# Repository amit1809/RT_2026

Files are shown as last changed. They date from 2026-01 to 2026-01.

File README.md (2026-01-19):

# RT-2025
CVHS Scioly Robot tour 2025

## Meeting recordings
https://drive.google.com/drive/folders/1aZCrpYOMPLyl0baIwFR1edMVWaG-CulE?usp=sharing

## Meeting notes
doces/RT-2025-meetings.pdf

## Example code
- stepper-without-lib
- stepper-with-lib
- buttons
- gyro (to be added)
- Robot (integrated with stepper lib, buttons)

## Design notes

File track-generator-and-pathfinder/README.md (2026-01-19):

# Track Generator

A Python tool for generating tracks and finding optimal paths.

- Track generation tool is from https://scioly.org/forums/viewforum.php?f=454
- Path finder tool is created deepseek v3 with vscode + cline

## Installation

1. Clone this repository:
   ```bash
   git clone https://github.com/frdeng/RT-2025.git
   cd RT-2025/track-generator
   ```

## Usage

The project contains two main scripts:

1. **pathfinder.py** - Contains pathfinding algorithms
2. **gen.py** - Contains track generation logic

Run the generator:
```bash
python gen.py
```

Run the pathfinder:
```bash
python pathfinder.py
```

## Contributing

Pull requests are welcome. For major changes, please open an issue first to discuss what you would like to change.

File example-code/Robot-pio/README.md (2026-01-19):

## Project Overview
### Key Components
- **src/main.cpp**: Main entry point for the robot, button and mode control
- **src/config.cpp**: Parameters and movement sequences
- **lib/Travel**: High-level movement sequencing and control
- **lib/Robot**: Motor control and movement execution
- **lib/IMU**: IMU integration and angle calculation
- **lib/Logger**: serial monitor logging and LCD screen display
- **lib/JY901**: IMU library

### Workflow
1. main.cpp loads parameters and sequences
1. Travel manages sequence execution
1. Robot controls stepper motors for movement, and IMU for angle feedback

## Setup

1. Install Visual Studio Code
https://visualstudio.microsoft.com/

1. Install PlatformIO IDE extension on VS Code
https://docs.platformio.org/en/latest/integration/ide/vscode.html#installation

1. Windows(not required for Mac)
Install ESP32 CP210x Driver: https://randomnerdtutorials.com/install-esp32-esp8266-usb-drivers-cp210x-windows/

## Operation Modes

1. **Test**
    - The robot will move with the test sequence defined in `src/config.cpp`

1. **Dry Run** (setDryRun(true))
    - Simulated movements
    - Timed turns

1. **Track Run**
    - The robot will move with the track sequence defined in `src/config.cpp`

## Quick Start

1. Copy configuration:
   ```bash
   cp src/config.cpp.example src/config.cpp
   ```

1. Adjust parameters in `src/config.cpp`
    - See Tuning Guide below

1. Modify `testSequence` or `runSequence` in `src/config.cpp` to define the sequence to run

1. Build and upload:
   - Click the upload button in the platformio IDE

5. Press the mode button on the robot to select the mode, place the robot on the track and press the start button to start the run

## Tuning Guide - `src/config.cpp`

1. **Basic Setup**
   - Set correct WHEEL_DISTANCE:  distance(in mmm) between the 2 driving wheels
   - Enable IMU-based turns: useIMU = true
   - Disable IMU-based turns: useIMU = false - switch to step-based turns

1. **Calibration for straight movement**

   This is to ensure your robot moves in a straight line.

   Steps to test and calibrate:
    - Update `testSequence` in `src/config.cpp` with `.f(2000).b(2000)`
    - Place the robot on a flat surface. Mark its starting position and orientation
    - Run the test sequence in TEST mode
    - Check the robot's final position and orientation, and compare with the starting position and orientation.
    - Loosen the screws on the stepper motor brackets and adjust them to align the wheels.
    - Repeat the process until the robot moves staight.

1. **Calibration for turns**

   Basics:
   - `Corrected target angle = target angle * LEFT_TURN_COMPENSATION or RIGHT_TURN_COMPENSATION`
   - The robot control code uses the corrected target angle to calculate the actual angle to turn.
   - For each turn, the angle read from the IMU is displayed in the serial monitor and on the LCD screen. This angle value(from IMU) should be close to the corrected target angle.
   - When the angle read from the IMU is over `0.03` degree off the corrected target angle, the color of the angle displayed on the LCD screen will be red.

   How to test the turns and adjust the compensation:
     - Update `testSequence` in `src/config.cpp` with 8 x 90° left turns (e.g. `.l().l().l().l().l().l().l().l()`)
     - Place the robot on a flat surface and mark its starting position and orientation
     - Run the test sequence in TEST mode
     - Monitor the angles displayed on the LCD screen after each turn
     - After sequence completion, check if robot returned to starting position/orientation
     - If left turns are off:
       - Increase `LEFT_TURN_COMPENSATION` if turns are too small
       - Decrease `LEFT_TURN_COMPENSATION` if turns are too large
     - If right turns are off:
       - Increase `RIGHT_TURN_COMPENSATION` if turns are too small  
       - Decrease `RIGHT_TURN_COMPENSATION` if turns are too large
     - Repeat above steps until robot reliably returns to the starting position and orientation.
     - Repeat the same process for 90° right turns (e.g. `.r().r().r().r().r().r().r().r()`)

1. **General PID Tuning for turns**
    - Start with only KP
    - Increase until slight oscillation
    - Add KD to reduce overshoot
    - Add KI if needed for precision

1. **Dry Run Timing for turns**

    The DRY_RUN mode allows testing the timing of a sequence without physically turning the robot. In this mode, the robot pauses for predefined durations from `DRY_RUN_STOP_TIMES` instead of executing actual turns. This helps validate sequence timing before running on the track.

    How to test the turns and adjust the timing:
    - Update `testSequence` in `src/config.cpp` with 8 x 90° left turns (e.g. `.l().l().l().l().l().l().l().l()`), and `totalStopTime` set to `0`.
    - Run the test sequence in TEST mode with cable connected to the robot, open serial monitor to monitor the times for each turn
    - Calculate the average time for each turn: `average_time = total run time / 8`
    - Update the `DRY_RUN_STOP_TIMES` array in `src/config.cpp` with the average time for each turn
    - Repeat above steps for all 45, 90, 135, 180 degree turns

## Troubleshooting

## Competition

### Preparation
1. Copy this `Robot-pio` folder to a USB drive or SD card
1. Make sure you are able to open the `Robot-pio` folder from the USB drive or SD card in VS Code
1. Make sure you are able to build and upload the code to the robot from VS Code using the USB drive or SD card
1. Fully charge the batteries, batteries should remain seperated from the robot
1. Put the robot, batteries, USB cable, USB drive or SD card, tools, extra parts in a box

### Competition
#### Setup time
1. Plug the USB drive or SD card into the robot
1. Open VS Code and select the `Robot-pio` folder from your USB drive or SD card
1. Open `src/config.cpp`, modify the `runSequence` to the sequence you want to run
1. Hold the robot, press the mode button to select the "Dry Run" mode
1. Read the total run time from the serial monitor or the LCD screen, if the run time is below the target run time, modify the `totalStopTime` in `src/config.cpp`, which is the `target run time - the total run time from dry run`.
1. Do another dry run to check if the run time is close to the target run time, if not, adjust the `totalStopTime` in `src/config.cpp` again.
#### Track time
1. Aftert the first successful run, adjust the distance of the final forward or backward movements, to make the robot stop closer to the target point.
1. Adjust the `totalStopTime` in `src/config.cpp` if needed

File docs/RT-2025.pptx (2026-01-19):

## Robot Tour

2024-25 CVHS Scioly

## Agenda

- Welcome and Introductions
- Team goals
- Overview of Robot tour
- Timeline
- Materials and Resources
- Robot Design Discussion
- Safety
- Team Policies
- Next steps and Assignments

## Welcome!

- Coaches
  - Frank Deng
    - https://www.linkedin.com/in/frankdeng/
    - 2nd year RT coach
  - Bryce Deng
- Team assignments (https://docs.google.com/spreadsheets/d/1oONcSgbaD9X0k0-0CMaOZCLKMwnZigFiKK7bTfDpvyY/edit?usp=sharing)

## Welcome!

- Green
  - Dylan Kwan
  - Jordan Tran
- Blue
  - Brandon Li
  - Eden Teclemariam
- Team assignments (https://docs.google.com/spreadsheets/d/1oONcSgbaD9X0k0-0CMaOZCLKMwnZigFiKK7bTfDpvyY/edit?usp=sharing)

## Welcome!

- Yellow
  - Arin Yang
  - Judah Chung
- Purple
  - Bryce Deng
  - Tulasi Venkatesh
- Team assignments (https://docs.google.com/spreadsheets/d/1oONcSgbaD9X0k0-0CMaOZCLKMwnZigFiKK7bTfDpvyY/edit?usp=sharing)

## Team goals

- Skills and knowledge
  - Mechanical and Electronics
  - Robotics engineering
  - Software development
- Innovation
  - Apply theoretical knowledge in practical ways
- Problem solving and troubleshooting
  - Identify and fix issues in design, programming
  - Iterative testing
- Teamwork and project management
  - Collaborative design
  - Time management

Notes: Consider talking about:
Box office
Critical response
Accolades

## Robot tour Overview

- https://www.soinc.org/robot-tour-c
- Science_Olympiad_Div_C_Rules_2025_for_Web_Secured.pdf (https://drive.google.com/file/d/1INkGKJuTZxSQCzLnRU0R5H9DXuwgUENu/view?usp=drivesdk)

## Robot tour Overview

- https://www.soinc.org/robot-tour-c
- Science_Olympiad_Div_C_Rules_2025_for_Web_Secured.pdf (https://drive.google.com/file/d/1INkGKJuTZxSQCzLnRU0R5H9DXuwgUENu/view?usp=drivesdk)

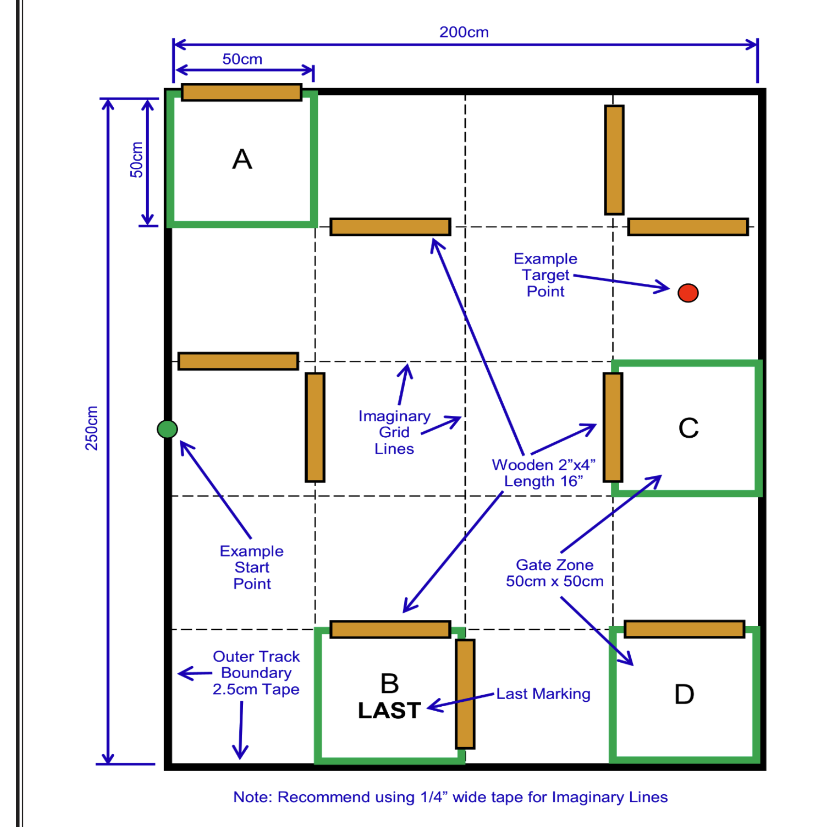
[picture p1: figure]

## Robot tour Overview

• Build an autonomous Robotic Vehicle to navigate a track
Not Remote Controlled
Event goals allow low cost robot kits to be competitive •
Powered by up to 6 AA or AAA batteries
Must completely fit in a 30cm by 30cm space of any height
•1/4” to 3/8” Dowel attached to front of Robotic Vehicle
Sensors
Alignment device

Build

## Robot tour Overview

• Impound
Track setup and target time released after impound
Setup Time: 10 min
Install batteries
Code and upload program
May only be tested provided the robot is held
Track Time: 8 mins
2 successful Runs or 3 failed runs

competition

## Robot tour Overview

• Track Area: 200 x 250 cm
4x5 = 20 imaginary square zones
Start point
Target point
Wooden obstacles – up to 10
Bonus gate zones
Regional: 4, States: 5, nationals 6
One gate zone is marked “last” (-15 pts vs -30 pts)
Target time: 55 – 85 seconds

Track

## Robot tour Overview

• Lowest final score wins
Final score = Time score + Distance score + Gate bonus + Last gate bonus + Penalties
Time score: 200
Less than target time: (target time – run time) x 2
Greater than target time: (run time – target time
Gate zone bonus: -15 pts
Last gate zone bonus: -30 pts
Penalties
Contact(obstacles): 70 pts
No obstacles: 50 pts
Stalling: 20 pts
Competition violation: 150pts
Construction violation: 300 pts

Scoring

## Robot tour Overview

• Track Area: 200x200 vs 200 x 250 cm
Target time: 55-75 secs vs 55 – 85 seconds
Distance score, 1 pts/cm vs 2 pts/cm
One more gate zone marked as “last”
Enter gate zone, forward, backward, sideways
Clear definition of Stalling

Key changes and updates
Q & A

## Timeline Milestone

- Sep – Nov
  - Theoretical study
    - Basic Mechanical principles
    - Electronics and power system basics
    - Arduino, ESP32
    - Motor, sensors and control loop systems
  - Activities
    - Programing with Arduino, motors, sensors
- Nov 2024 – Feb 2025
  - Build
    - Build your robot
    - Build your program
  - Activities
    - Practice
    - Competitions – Invitationals, Regionals

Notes: Consider talking about:
Box office
Critical response
Accolades

## Materials Resources

- Event home page https://www.soinc.org/robot-tour-c
- Forum https://scioly.org/forums/viewforum.php?f=454
- FAQ https://www.soinc.org/faq/robot-tour-div-c
- Science Olympiad community discord server – robot tour channel https://discord.gg/fPXJHnm9DE
- Youtube – search “scioly robot tour”

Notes: Consider talking about:
Home media

## Safety

- Electrical
  - Batteries
  - Circuit
  - Motors
- Tool usage
  - Cutting
  - Soldering
- Storage

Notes: Consider talking about:
Home media

## Team polices

- Rules
- Meetings
- Communication
  - Discord RT channel

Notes: Consider talking about:
Home media

## Next steps Assignments

- Wrap-up
- Final question
- Next meeting time and location
- Action items
  - Github account, create private repository

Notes: Consider talking about:
Score

## ”Good Luck"

Robot tour

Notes: Quotes by Robots:
"No."
"What?"
"Yes."
"For what?"
"Thanks."
"Oh!"
"Or..."
"But..."
"No"
"Come on!"

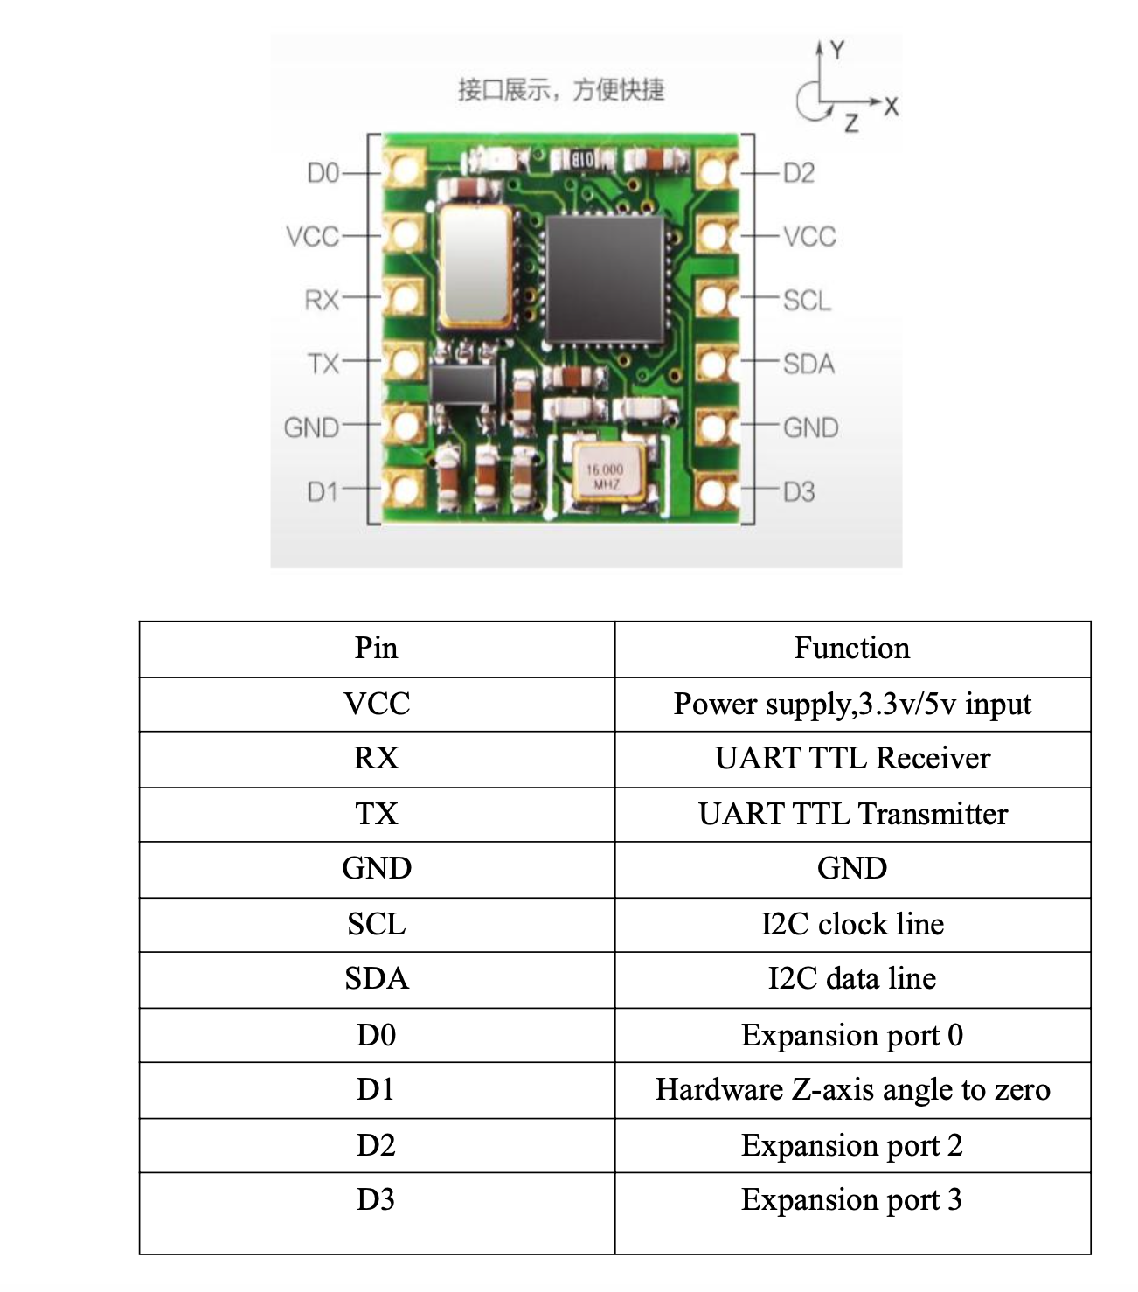
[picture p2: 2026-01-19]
docs/IMU.png

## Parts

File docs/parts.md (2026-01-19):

## Microcontroller - ESP32
- model: ESP32-WROOM-32D
- spec: 
  - Chip: https://www.espressif.com/sites/default/files/documentation/esp32_datasheet_en.pdf
  - MCU module https://www.espressif.com/sites/default/files/documentation/esp32-wroom-32d_esp32-wroom-32u_datasheet_en.pdf

- docs
  - https://docs.espressif.com/projects/esp-dev-kits/en/latest/esp32/esp32-devkitc/index.html
  - https://docs.espressif.com/projects/arduino-esp32/en/latest/getting_started.html

## Stepper motor and motor driver

### Stepper Motor - NEMA 17
- model: 17HS3430S
- spec: https://www.aliexpress.us/item/3256806265226544.html?gatewayAdapt=glo2usa4itemAdapt#nav-specification

### Motor driver - TMC2208
- spec: https://www.analog.com/en/products/tmc2208.html

### Guide
- Set Vref https://www.circuitist.com/how-to-set-driver-current-a4988-drv8825-tmc2208-tmc2209/
- https://howtomechatronics.com/tutorials/arduino/stepper-motors-and-arduino-the-ultimate-guide/

## 3-pin button
- doc: https://arduinomodules.info/ky-004-key-switch-module/

## Gyro sensor(Optional)
To be added

## Laser module(Optional)
### 3-pin laser
- doc
  - https://www.build-electronic-circuits.com/arduino-laser-module-ky-008/
  - https://srituhobby.com/laser-transmitter-and-receiver-module-with-arduino/

## TFT display(Optional)
- model: ST7735S, size 0.96 inch, resolution: 160x80
- doc
  - https://www.devacron.com/2022/06/27/add-an-st7735-tft-display-to-an-esp32/
  -

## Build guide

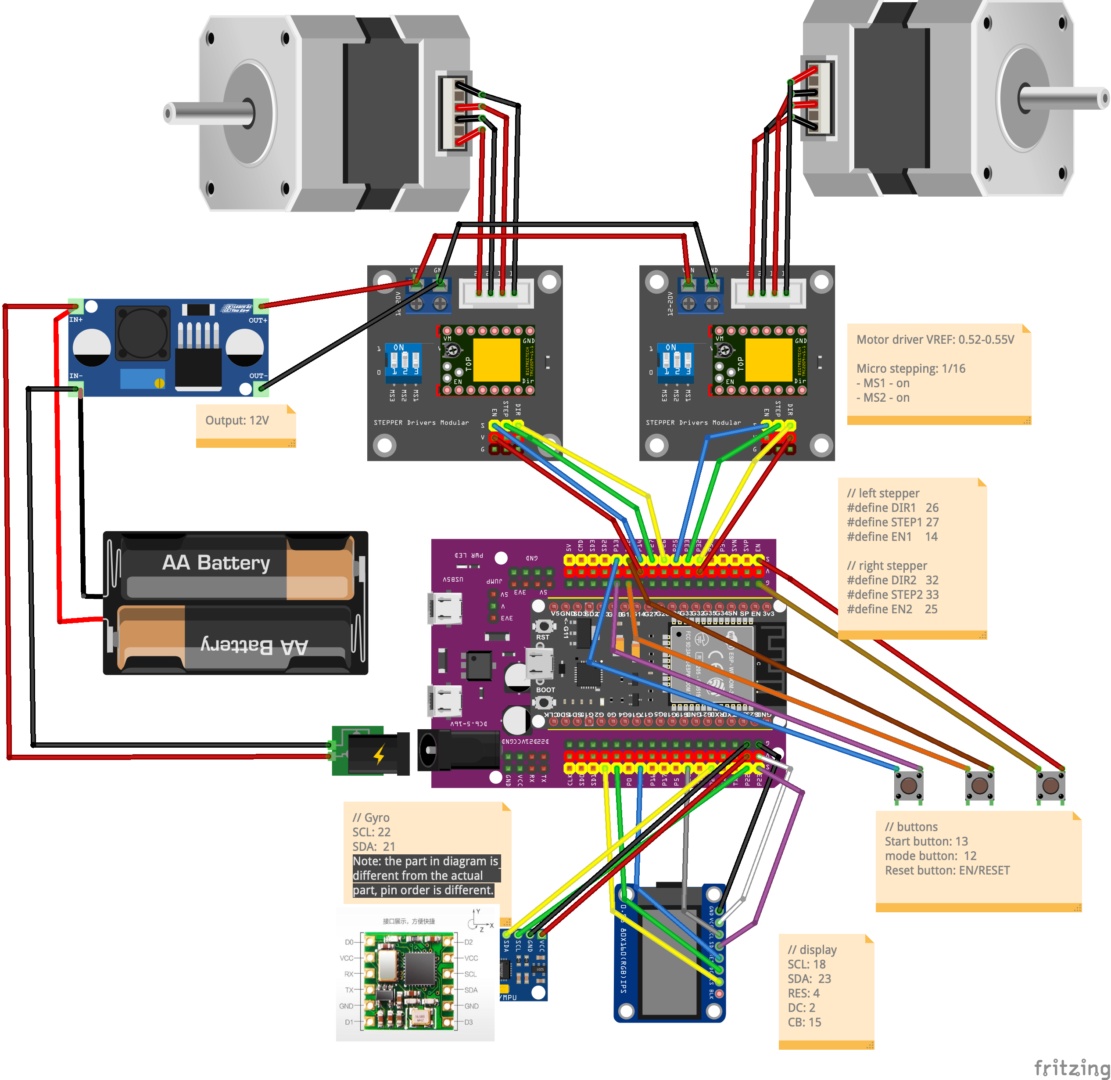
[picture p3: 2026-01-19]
docs/S2-wiring.png

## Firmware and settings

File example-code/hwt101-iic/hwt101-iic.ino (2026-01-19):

#include <Arduino.h>
#include <Wire.h>
#include "REG.h"
#include "wit_c_sdk.h"

/*
Test on ESP32, HTW101 sensor

 JY901S           ESP32-WROOM-32
  VCC      <--->   5V/3.3V
  SCL      <--->   SCL(22)
  SDA      <--->   SDA(21)
  GND      <--->    GND
*/

#define ACC_UPDATE		0x01
#define GYRO_UPDATE		0x02
#define ANGLE_UPDATE	0x04
#define MAG_UPDATE		0x08
#define READ_UPDATE		0x80
static char s_cDataUpdate = 0, s_cCmd = 0xff;

static void CmdProcess(void);
static void AutoScanSensor(void);
static void SensorUartSend(uint8_t *p_data, uint32_t uiSize);
static void CopeSensorData(uint32_t uiReg, uint32_t uiRegNum);
static int32_t IICreadBytes(uint8_t dev, uint8_t reg, uint8_t *data, uint32_t length);
static int32_t IICwriteBytes(uint8_t dev, uint8_t reg, uint8_t* data, uint32_t length);
static void Delayms(uint16_t ucMs);

void setup() {
  // put your setup code here, to run once:
  Wire.begin();
  Wire.setClock(400000);
	Serial.begin(115200);
	WitInit(WIT_PROTOCOL_I2C, 0x50);
	WitI2cFuncRegister(IICwriteBytes, IICreadBytes);
	WitRegisterCallBack(CopeSensorData);
  WitDelayMsRegister(Delayms);
	Serial.print("\r\n********************** wit-motion IIC example  ************************\r\n");
	AutoScanSensor();
}
int i;
float fAcc[3], fGyro[3], fAngle[3];
void loop() {
    WitReadReg(AX, 12);
    delay(500);
    while (Serial.available()) 
    {
      CopeCmdData(Serial.read());
    }
		CmdProcess();
		if(s_cDataUpdate)
		{
			for(i = 0; i < 3; i++)
			{
				fAcc[i] = sReg[AX+i] / 32768.0f * 16.0f;
				fGyro[i] = sReg[GX+i] / 32768.0f * 2000.0f;
				fAngle[i] = sReg[Roll+i] / 32768.0f * 180.0f;
			}
			if(s_cDataUpdate & ACC_UPDATE)
			{
				Serial.print("acc:");
				Serial.print(fAcc[0], 3);
				Serial.print(" ");
				Serial.print(fAcc[1], 3);
				Serial.print(" ");
				Serial.print(fAcc[2], 3);
				Serial.print("\r\n");
				s_cDataUpdate &= ~ACC_UPDATE;
			}
			if(s_cDataUpdate & GYRO_UPDATE)
			{
				Serial.print("gyro:");
				Serial.print(fGyro[0], 1);
				Serial.print(" ");
				Serial.print(fGyro[1], 1);
				Serial.print(" ");
				Serial.print(fGyro[2], 1);
				Serial.print("\r\n");
				s_cDataUpdate &= ~GYRO_UPDATE;
			}
			if(s_cDataUpdate & ANGLE_UPDATE)
			{
				Serial.print("angle:");
				Serial.print(fAngle[0], 3);
				Serial.print(" ");
				Serial.print(fAngle[1], 3);
				Serial.print(" ");
				Serial.print(fAngle[2], 3);
				Serial.print("\r\n");
				s_cDataUpdate &= ~ANGLE_UPDATE;
			}
			if(s_cDataUpdate & MAG_UPDATE)
			{
				Serial.print("mag:");
				Serial.print(sReg[HX]);
				Serial.print(" ");
				Serial.print(sReg[HY]);
				Serial.print(" ");
				Serial.print(sReg[HZ]);
				Serial.print("\r\n");
				s_cDataUpdate &= ~MAG_UPDATE;
			}
      s_cDataUpdate = 0;
		}
}


void CopeCmdData(unsigned char ucData)
{
	static unsigned char s_ucData[50], s_ucRxCnt = 0;
	
	s_ucData[s_ucRxCnt++] = ucData;
	if(s_ucRxCnt<3)return;										//Less than three data returned
	if(s_ucRxCnt >= 50) s_ucRxCnt = 0;
	if(s_ucRxCnt >= 3)
	{
		if((s_ucData[1] == '\r') && (s_ucData[2] == '\n'))
		{
			s_cCmd = s_ucData[0];
			memset(s_ucData,0,50);
			s_ucRxCnt = 0;
		}
		else 
		{
			s_ucData[0] = s_ucData[1];
			s_ucData[1] = s_ucData[2];
			s_ucRxCnt = 2;
			
		}
	}
}

static int32_t IICreadBytes(uint8_t dev, uint8_t reg, uint8_t *data, uint32_t length)
{
	int val;
    Wire.beginTransmission(dev);
    Wire.write(reg);
    Wire.endTransmission(false); //endTransmission but keep the connection active

    val = Wire.requestFrom(dev, length); //Ask for bytes, once done, bus is released by default

	if(val == 0)return 0;
    while(Wire.available() < length) //Hang out until we get the # of bytes we expect
      ;

    for(int x = 0 ; x < length ; x++)    data[x] = Wire.read();   

    return 1;
}


static int32_t IICwriteBytes(uint8_t dev, uint8_t reg, uint8_t* data, uint32_t length)
{
    Wire.beginTransmission(dev);
    Wire.write(reg);
    Wire.write(data, length);
    Wire.endTransmission(); //Stop transmitting

    return 1; 
}

static void ShowHelp(void)
{
	Serial.print("\r\n************************	 WIT_SDK_DEMO	************************");
	Serial.print("\r\n************************          HELP           ************************\r\n");
	Serial.print("UART SEND:a\\r\\n   Acceleration calibration.\r\n");
	Serial.print("UART SEND:m\\r\\n   Magnetic field calibration,After calibration send:   e\\r\\n   to indicate the end\r\n");
	Serial.print("UART SEND:U\\r\\n   Bandwidth increase.\r\n");
	Serial.print("UART SEND:u\\r\\n   Bandwidth reduction.\r\n");
	Serial.print("UART SEND:B\\r\\n   Baud rate increased to 115200.\r\n");
	Serial.print("UART SEND:b\\r\\n   Baud rate reduction to 9600.\r\n");
	Serial.print("UART SEND:h\\r\\n   help.\r\n");
	Serial.print("******************************************************************************\r\n");
}

static void CmdProcess(void)
{
	switch(s_cCmd)
	{
		case 'a':	if(WitStartAccCali() != WIT_HAL_OK) Serial.print("\r\nSet AccCali Error\r\n");
			break;
		case 'm':	if(WitStartMagCali() != WIT_HAL_OK) Serial.print("\r\nSet MagCali Error\r\n");
			break;
		case 'e':	if(WitStopMagCali() != WIT_HAL_OK) Serial.print("\r\nSet MagCali Error\r\n");
			break;
		case 'u':	if(WitSetBandwidth(BANDWIDTH_5HZ) != WIT_HAL_OK) Serial.print("\r\nSet Bandwidth Error\r\n");
			break;
		case 'U':	if(WitSetBandwidth(BANDWIDTH_256HZ) != WIT_HAL_OK) Serial.print("\r\nSet Bandwidth Error\r\n");
			break;
    case 'B': if(WitSetUartBaud(WIT_BAUD_115200) != WIT_HAL_OK) Serial.print("\r\nSet Baud Error\r\n");
              else Serial.print(" 115200 Baud rate modified successfully\r\n");
      break;
    case 'b': if(WitSetUartBaud(WIT_BAUD_9600) != WIT_HAL_OK) Serial.print("\r\nSet Baud Error\r\n");
              else Serial.print(" 9600 Baud rate modified successfully\r\n");
      break;
		case 'N':	if(WitSetOutputRate(RRATE_ONCE) != WIT_HAL_OK) Serial.print("\r\nSet Baud Error\r\n");
              else Serial.print("\r\nSet output rate Success\r\n");
    case 't':
        if (WitStartRKMODECali() != WIT_HAL_OK)
            printf("\r\nSart RKMODECali Error\r\n");
        else
            printf("\r\Start RKMODECali Success\r\n");
        break;
    case 'T':
        if (WitStopRKMODECali() != WIT_HAL_OK)
            printf("\r\nStop RKMODECali Error\r\n");
        else
            printf("\r\Stop RKMODECali Success\r\n");
        break;
    case 'S':
        if (WitSetAngleRange() != WIT_HAL_OK)
          printf("\r\nSetAngleRange Error\r\n");
        else
          printf("\r\nSetAngleRange Success\r\n");
        break;
    case 'F':
        if (WitReset() != WIT_HAL_OK)
          printf("\r\nFReset Error\r\n");
        else
          printf("\r\nFReset Success\r\n");
        break;
		case 'R':	if(WitStartIYAWCali() != WIT_HAL_OK) Serial.print("\r\nWitStartIYAWCali Error\r\n");
              else Serial.print("\r\nWitStartIYAWCali Success\r\n");
			  break;
		case 'h':	ShowHelp();
			break;
		default :return;
	}
	s_cCmd = 0xff;
}

static void CopeSensorData(uint32_t uiReg, uint32_t uiRegNum)
{
	int i;
    for(i = 0; i < uiRegNum; i++)
    {
        switch(uiReg)
        {
            case AZ:
				s_cDataUpdate |= ACC_UPDATE;
            break;
            case GZ:
				s_cDataUpdate |= GYRO_UPDATE;
            break;
            case HZ:
				s_cDataUpdate |= MAG_UPDATE;
            break;
            case Yaw:
				s_cDataUpdate |= ANGLE_UPDATE;
            break;
            default:
				s_cDataUpdate |= READ_UPDATE;
			break;
        }
		uiReg++;
    }
}

static void Delayms(uint16_t ucMs)
{
  delay(ucMs);
}


static void AutoScanSensor(void)
{
	int i, iRetry;
	
	for(i = 0; i < 0x7F; i++)
	{
		WitInit(WIT_PROTOCOL_I2C, i);
		iRetry = 2;
		do
		{
			s_cDataUpdate = 0;
			WitReadReg(AX, 3);
			delay(5);
			if(s_cDataUpdate != 0)
			{
				Serial.print("find 0x");
				Serial.print(i, HEX);
				Serial.print(" addr sensor\r\n");
				ShowHelp();
				return ;
			}
			iRetry--;
		}while(iRetry);		
	}
	Serial.print("can not find sensor\r\n");
	Serial.print("please check your connection\r\n");
}

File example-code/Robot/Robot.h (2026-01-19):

#ifndef ROBOT_H
#define ROBOT_H

#include <Arduino.h>
#include <AccelStepper.h>
#include "Logger.h"

// define pins
// left stepper
#define DIR1 26
#define STEP1 27
#define EN1 14

// right stepper
#define DIR2 32
#define STEP2 33
#define EN2 25

// stepper parameters
#define STEPS_PER_REVOLUTION 200
// micro stepping - TMC2208
/*
 * MS1  MS2  STEPS
 * HIGH LOW  1/2
 * LOW  HIGH 1/4
 * LOW  LOW  1/8
 * HIGH HIGH 1/16 - use this
 */
#define MICRO_STEPS 16
// speed
// move
#define MOVE_SPEED (400 * MICRO_STEPS)
#define MOVE_ACCEL (MOVE_SPEED * 1.5)

// turn
#define TURN_SPEED (MOVE_SPEED * 0.5)
#define TURN_ACCEL (TURN_SPEED * 1.5)

// Robot parameters
// 200mm wheel circumference
#define WHEEL_CIRCUMFERENCE 200
// 140mm wheel distance - distance between 2 wheels
#define WHEEL_DISTANCE 140

// movement timeout - 10 seconds
#define MOVEMENT_TIMEOUT 10000
// max distance - 1000mm
#define MAX_DISTANCE 1000

// max angle - 360 degrees
#define MAX_ANGLE 360.0

class Robot
{
private:
  AccelStepper _leftStepper;
  AccelStepper _rightStepper;

public:
  Robot()
      : _leftStepper(AccelStepper::DRIVER, STEP1, DIR1),
        _rightStepper(AccelStepper::DRIVER, STEP2, DIR2)
  {
    // init stepper EN pins
    pinMode(EN1, OUTPUT);
    pinMode(EN2, OUTPUT);
    turnOffSteppers();
  }

  void turnOnSteppers()
  {
    logger.info("Turning on steppers");
    digitalWrite(EN1, LOW);
    digitalWrite(EN2, LOW);
  }

  void turnOffSteppers()
  {
    logger.info("Turning off steppers");
    digitalWrite(EN1, HIGH);
    digitalWrite(EN2, HIGH);
    _leftStepper.setCurrentPosition(0);
    _rightStepper.setCurrentPosition(0);
  }

  void move(long distance)
  {
    if (abs(distance) > MAX_DISTANCE)
    {
      logger.error("Distance exceeds maximum limit");
      return;
    }
    long target_pos = distance * MICRO_STEPS;
    logger.info("Moving to %dmm (%d steps)", distance, target_pos);

    _leftStepper.setCurrentPosition(0);
    _rightStepper.setCurrentPosition(0);

    _leftStepper.setMaxSpeed(MOVE_SPEED);
    _rightStepper.setMaxSpeed(MOVE_SPEED);
    _leftStepper.setAcceleration(MOVE_ACCEL);
    _rightStepper.setAcceleration(MOVE_ACCEL);

    _leftStepper.moveTo(target_pos);
    _rightStepper.moveTo(-target_pos);

    unsigned long startTime = millis();
    while (_leftStepper.currentPosition() != target_pos)
    {
      if (millis() - startTime > MOVEMENT_TIMEOUT)
      {
        logger.error("Movement timeout");
        break;
      }
      _leftStepper.run();
      _rightStepper.run();
    }
  }

  void turn(double angle = 90.0)
  {
    if (abs(angle) > MAX_ANGLE)
    {
      logger.error("Angle exceeds maximum limit");
      return;
    }
    logger.info("Turning %D degrees", angle);

    // Calculate steps for turning: (angle/360°) * (π*wheel_distance) * (steps_per_mm)
    double distance_per_wheel = (angle / 360.0) * (PI * WHEEL_DISTANCE);
    long steps = distance_per_wheel * (STEPS_PER_REVOLUTION * MICRO_STEPS / WHEEL_CIRCUMFERENCE);

    _leftStepper.setCurrentPosition(0);
    _rightStepper.setCurrentPosition(0);

    _leftStepper.setMaxSpeed(TURN_SPEED);
    _rightStepper.setMaxSpeed(TURN_SPEED);
    _leftStepper.setAcceleration(TURN_ACCEL);
    _rightStepper.setAcceleration(TURN_ACCEL);

    _leftStepper.moveTo(steps);
    _rightStepper.moveTo(steps);

    unsigned long startTime = millis();
    while (_leftStepper.currentPosition() != steps)
    {
      if (millis() - startTime > MOVEMENT_TIMEOUT)
      {
        logger.error("Turn timeout");
        break;
      }
      _leftStepper.run();
      _rightStepper.run();
    }
  }

  void stop(unsigned long duration)
  {
    logger.info("Stopping %u ms", duration);
    delay(duration);
  }
};

#endif

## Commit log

2026-01-19 add code
    [S2.fzz]
2026-02-19 final working after wire changes
